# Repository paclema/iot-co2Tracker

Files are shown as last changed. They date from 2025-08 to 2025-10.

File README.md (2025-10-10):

# IoT-CO2Tracker

The IoT-CO2Tracker is a compact device that measures CO₂, temperature, and humidity. Initially developed on an ESP8266, it was later moved to an ESP32 using the IoT-PostBox board. The project also serves to validate the board's capabilities, though that is not its primary purpose.

An external GPS module can be connected via the serial port, allowing the device to publish both sensor readings and location data. This data is sent via LoRaWAN to The Things Network (TTN) for coverage and connectivity analysis, and over Wi-Fi using MQTT to your own broker. When needed, GPS tracks are logged to the onboard flash storage and can be downloaded for visualization through a built-in FTP server. The latest hardware revision includes a 2" TFT screen that displays live sensor values, connectivity, and battery status, with a user interface built on LVGL v9 and designed with SquareLine.

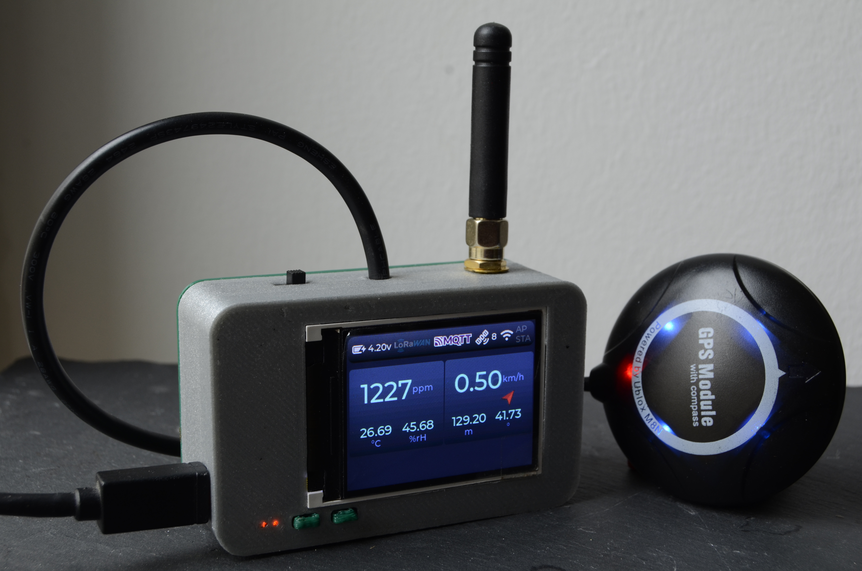
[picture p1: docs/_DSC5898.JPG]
IoT-CO2Tracker


---

## Communication flow

```mermaid
flowchart LR
  	Device[IoT-CO2Tracker]
	Broker[(MQTT Broker)]
	GW[LoRaWAN Gateway]
	TTN[The Things Network]
	NR[Node-RED]
	HA[Home Assistant]
	DB[(InfluxDB)]
	G[Grafana]
	Flash[(LittleFS)]
	PC[PC]
	Viz[GPSVisualizer]

	Device -- MQTT (JSON) --> Broker
	Broker --> NR
	Device -- LoRaWAN (binary) --> GW --> TTN --> NR
	NR --> DB --> G
		NR -.->|update device*| HA

	Device -- GPS tracks --> Flash -- FTP download --> PC --> Viz
```

<sub>* planned (to be implemented)</sub>

### MQTT
- Topic: `/iot-co2Tracker/<deviceId>/data`

Example payload (without GPS):

```json
{
	"CO2": 222,
	"temp": 33.02967834,
	"humidity": 30.82733154,
	"rssi_STA": -38,
	"vBat": 4.21023798,
	"vBus": 5.021749973,
	"PowerStatus": 2,
	"ChargingStatus": 2
}
```

Example payload (with GPS):

```json
{
	"CO2": 229,
	"temp": 31.5396347,
	"humidity": 29.40368652,
	"lat": 51.27265917,
	"lng": 12.37718133,
	"date": 120925,
	"time": 15070704,
	"speed": 0.11112,
	"satellites": 4,
	"altitude": 197.6,
	"hdop": 8.33,
	"course": 120925,
	"rssi_STA": -54,
	"vBat": 4.116175175,
	"vBus": 0.01325,
	"PowerStatus": 3,
	"ChargingStatus": 1
}
```

### LoRaWAN uplink

| Field | C type | Bytes | Units | Notes |
|---|---|---|---|---|
| latitude | uint32_t | 4 | degrees | 24-bit value scaled to 4 bytes ((lat+90)/180*16777215) |
| longitude | uint32_t | 4 | degrees | 24-bit value scaled to 4 bytes ((lng+180)/360*16777215) |
| altitude | uint16_t | 2 | m |  |
| hdop | uint16_t | 2 | HDOP |  |
| speed | uint16_t | 2 | km/h | value = km/h × 100 |
| satellites | uint8_t | 1 | count |  |
| course | uint16_t | 2 | degrees |  |
| time | uint32_t | 4 | HHMMSScc  | local offset applied |
| vBat | uint16_t | 2 | mV |  |
| vBus | uint16_t | 2 | mV |  |
| CO2 | uint16_t | 2 | ppm |  |
| temp | uint16_t | 2 | °C | value = °C × 100 |
| hum | uint16_t | 2 | % | value = % × 100 |
| powerStatus | uint8_t | 1 | enum |  |
| chargingStatus | uint8_t | 1 | enum |  |

Notes
- Multi-byte fields are big-endian (MSB first).
- Latitude/Longitude use 24-bit effective values packed into 4 bytes (high byte may be 0).
- Total payload length: 33 bytes.

Decoders: see [formaters/](formaters/) for TTN uplink decoders and field mapping.

TTN setup (OTAA)
1. Create an application `co2Tracker` and register a device.
2. Set the device DEVEUI, APPEUI, and APPKEY to your `config.json`.
3. Add the custom uplink decoder from [formaters/custom](formaters/custom) to your TTN application.
4. Join the device and verify uplinks in the TTN console under the [Application live data tab](https://eu1.cloud.thethings.network/console/applications/co2tracker/data).

### FTP GPS logs
- If the `local_logs` configuration is enabled in the [config.json](data/config/config.json) file, GPS log files will be created on the LittleFS partition. The file names will follow a specific naming convention, such as [`GPS_2025_9_10.csv`](/docs/GPS_2025_9_10.csv).
- Connect via FTP to the device server using the username and password configured in [config.json](data/config/config.json) to download the GPS log file.
- CSV columns follow:

```csv
time,latitude,longitude,altitude,speed,hdop,satellites,course,vBat,vBus,PowerStatus,ChargingStatus,co2,temp,hum
18182040,51.27235567,12.37730017,115.1,31.503,1.06,12,162.6,3.98449,0.00795,1,2,239,22.34,57.10
18182553,51.27197583,12.37750567,115.6,31.540,1.06,12,162.8,3.98449,0.00795,1,2,232,22.34,57.15
18183040,51.27155317,12.37771250,116.4,29.595,1.06,12,167.4,3.98073,0.00795,1,2,221,22.36,57.19
18183541,51.27119583,12.37782367,117.2,29.058,1.15,12,167.5,3.98073,0.00795,1,2,207,22.38,57.31
```
- You can visualize the GPS tracks using tools like [GPSVisualizer](http://www.gpsvisualizer.com/) by uploading the CSV file. A good filter in this case can the [IoT-CO2Tracker GPSVisualizer configuration](https://www.gpsvisualizer.com/map_input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) option.

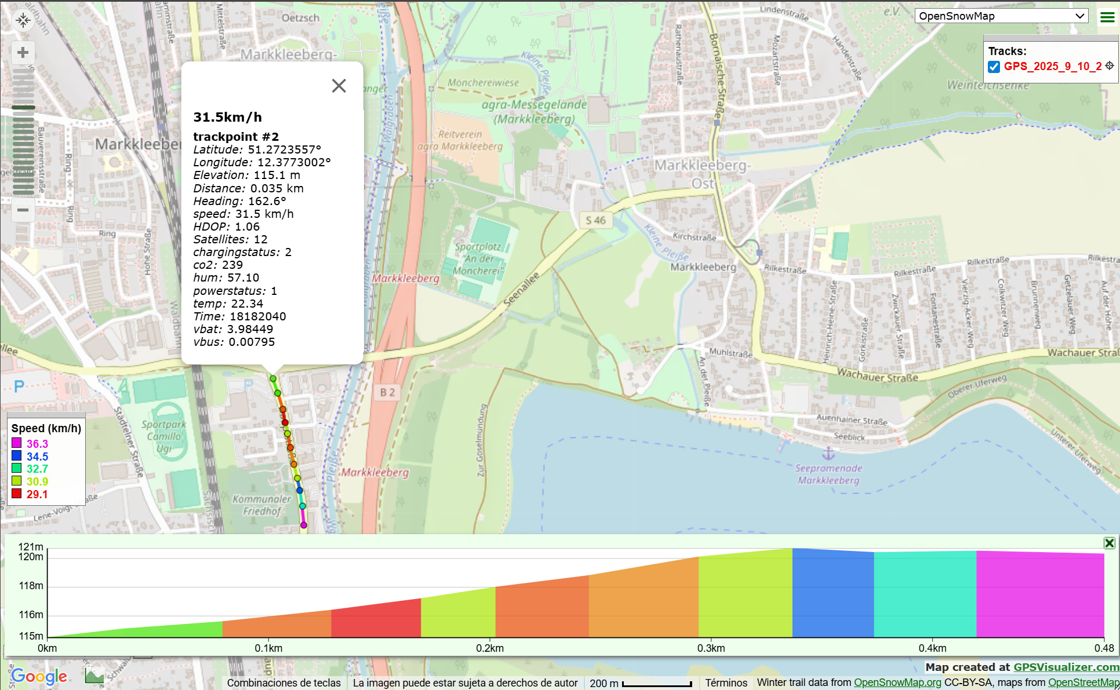
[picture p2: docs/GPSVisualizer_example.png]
GPSVisualizer_example

---

## Software

### Firmware
- PlatformIO project (ESP32). FreeRTOS tasks for sensors, UI, and communications.
- Main Libraries used: 
  - [WebConfigServer](https://github.com/paclema/WebConfigServer): to configure the device settings over a web interface and manage multiple common services
  - [MQTTClient](https://github.com/paclema/MQTTClient): MQTT client library
  - [LoRaWANClient](https://github.com/paclema/LoRaWANClient): LoRaWAN C++ client based on [Arduino-LMIC](https://github.com/mcci-catena/arduino-lmic)
  - [PowerManagement](https://github.com/paclema/PowerManagement): power management library to read battery and power states
  - [SparkFun SCD30](https://github.com/sparkfun/SparkFun_SCD30_Arduino_Library): read CO₂, temperature, and humidity from the SCD30 sensor
  - [TinyGPSPlus](https://github.com/mikalhart/TinyGPSPlus): parse GPS data

### Display & User Interface (UI-LCD)

- Designed for a 2.0" GMT020-02 TFT SPI LCD (ST7789V driver, non-touch).
- Uses LVGL v9.
- Interface designed with SquareLine. The project can be found under [`SquareLineProject/`](SquareLineProject/).

<p align="center">
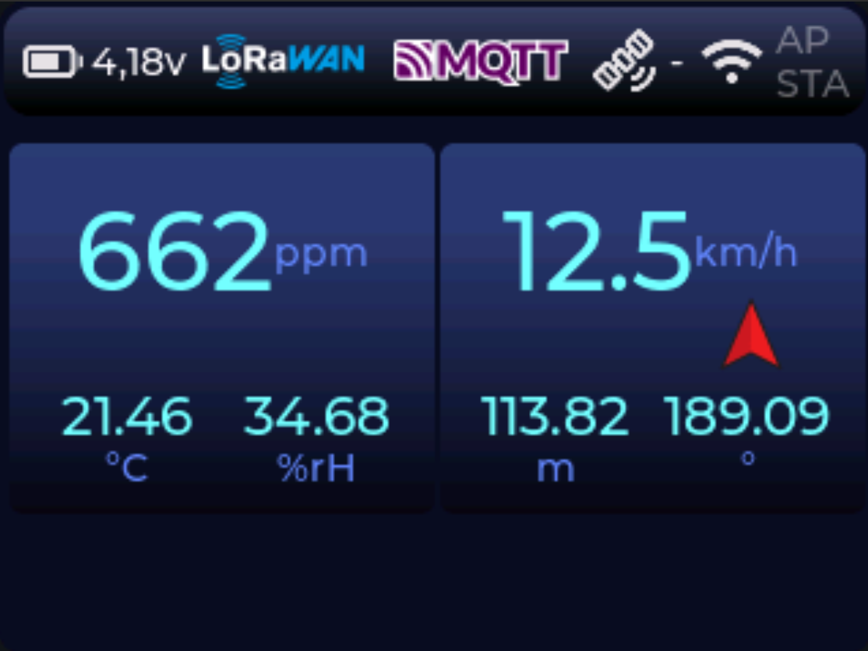
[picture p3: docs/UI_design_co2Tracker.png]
UI Design
  
</p>

### Backend services

- **Node-RED** subscribes to MQTT and TTN, processes messages, and stores data values in InfluxDB (requires [node-red-contrib-influxdb](https://flows.nodered.org/node/node-red-contrib-influxdb) node installation).
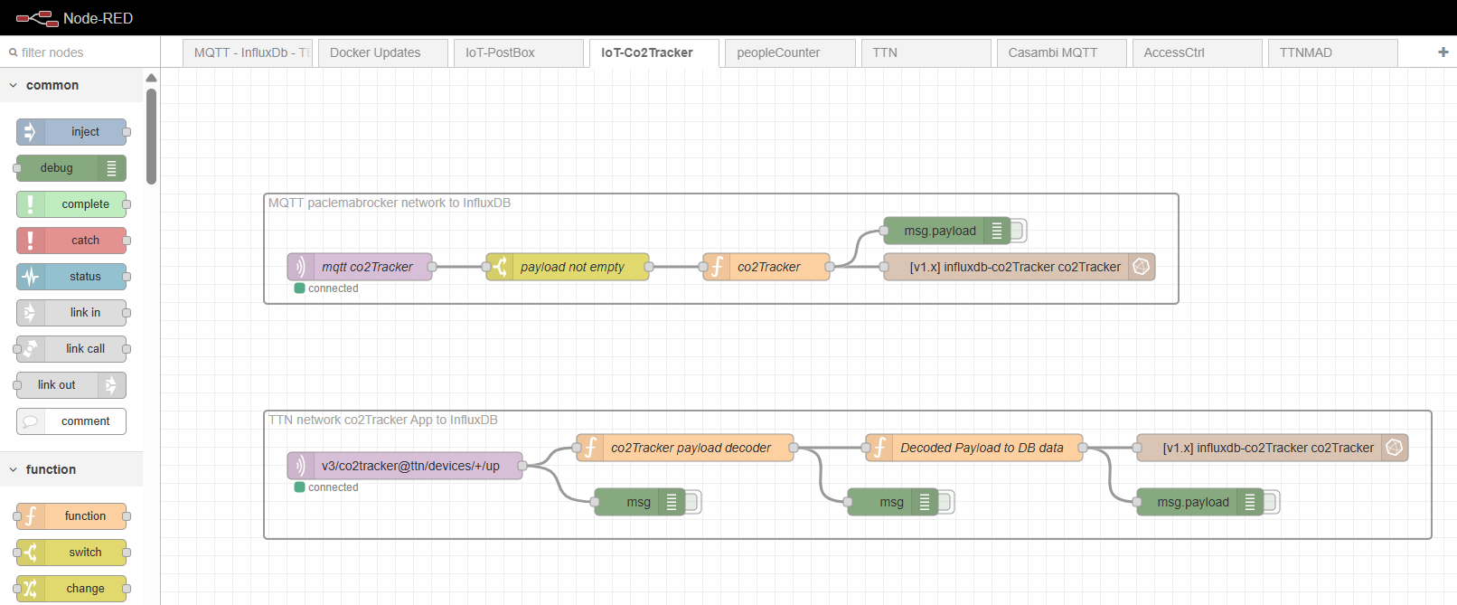
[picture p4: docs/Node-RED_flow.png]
Node-RED_flow

- Example Node-RED flow: [backend/nodered/flows.json](backend/nodered/flows.json)
- **Grafana** dashboards read from InfluxDB.
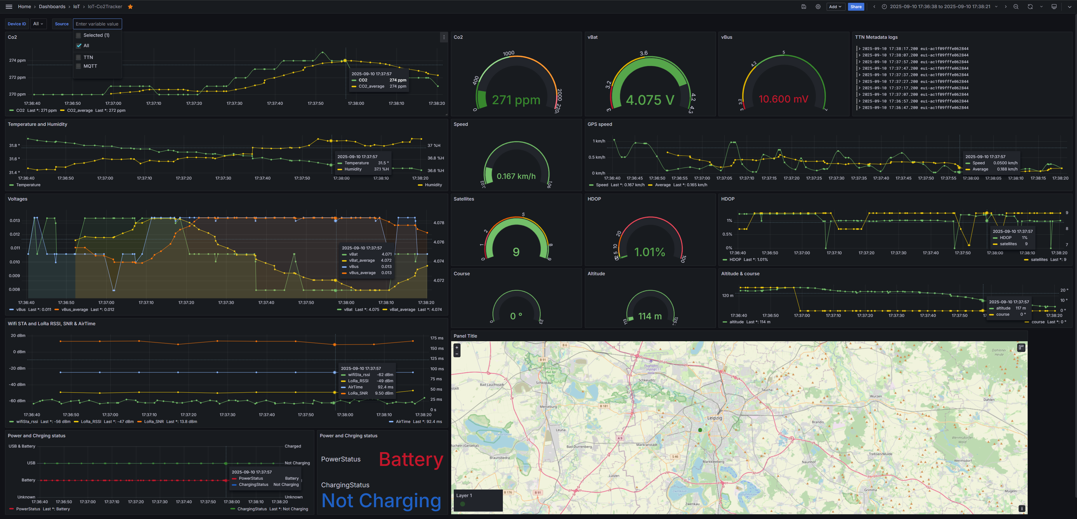
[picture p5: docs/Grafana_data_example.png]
Grafana_data_example

- Example Grafana dashboard: [backend/grafana/IoT-Co2Tracker_dashboard.json](backend/grafana/IoT-Co2Tracker_dashboard.json)
- **TTN formatters**: see decoders in [formaters/](formaters/) for field mapping.

---

## Hardware

### Main Components

The essential hardware components for this project include:
- Board: IoT-PostBox (ESP32/ESP32-S2 with onboard RFM95W LoRa module)
- Sensor: SCD30 (CO₂, temperature, humidity) over I²C
- GPS (optional): u-blox M8N or compatible GPS module using serial UART
- Display (optional): 2.0" GMT020-02 TFT OLED SPI LCD with ST7789V driver
- Power: battery support with charging capabilities using IoT-PostBox

### 3D Design & Enclosure

- FreeCAD sources in [3Ddesigns/](3Ddesigns/)
- External STL references documented in [3Ddesigns/lib/readme.md](3Ddesigns/lib/readme.md).

### Pinout

Pinout highlights (see [boards/](boards/) and [boards/variants/iotpostbox_v1/](boards/variants/iotpostbox_v1/) for full mapping)

**TODO: add pinout diagram**

---

## Build & flash
1. Open the project using PlatformIO with VS Code.
2. Configure services and device following the [WebConfigServer](https://github.com/paclema/WebConfigServer) style, editing the [`data/config/config.json`](/data/config/config.json) and uploading the Filesystem Image to the device.
3. Build and upload the firmware to an IoT-PostBox device.
4. Use the device WebConfigServer UI web portal for advanced options.

---

This repo is derived from [iot_button#CO2_tracker](https://github.com/paclema/iot_button/tree/CO2_tracker)

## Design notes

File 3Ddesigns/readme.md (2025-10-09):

# co2Tracker Case

This folder contains the FreeCAD design files and exported assets for the enclosure of the co2Tracker device.

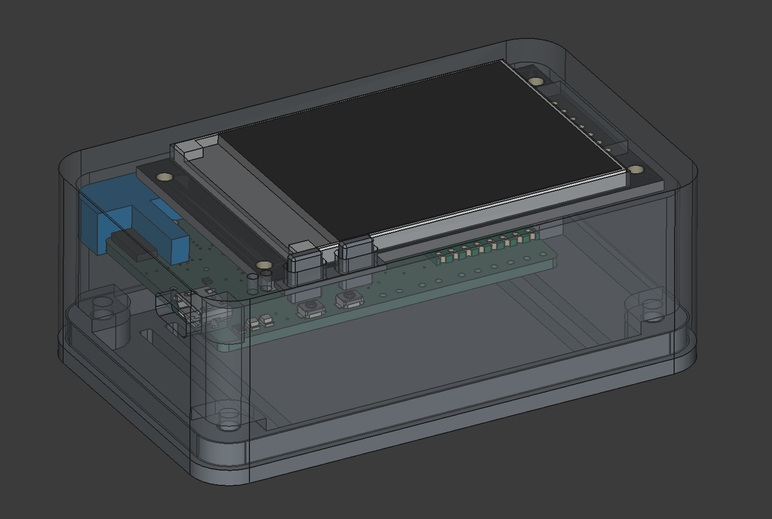
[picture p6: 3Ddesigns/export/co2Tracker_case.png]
Case Render


## Contents

- **FreeCAD Project:**  
  - `co2Tracker_case.FCStd` — Main editable FreeCAD file for the enclosure design.

- **Exports:**  
  - `co2Tracker_case_Top.stl` — STL file for the top part of the case.
  - `co2Tracker_case_Bottom.stl` — STL file for the bottom part of the case.
  - `co2Tracker_case_Board_spacer.stl` — Spacer for mounting the board.
  - `co2Tracker_case_Buttons_extender.stl` — Extender for external buttons.

## Description

The case is designed to fit the IoT-PostBox board, SCD30 sensor, GPS module, TFT display, and a 1100mAh LiPo battery.  
It provides protection and mounting points for all components, with cutouts for the display, connectors, and ventilation for the CO₂ sensor.

**Rear Features:**  
- Holes for mounting the LoRa antenna  
- Cutout for a switch to activate the battery  
- Opening for routing the cable of the external GPS module

**Parametric Design:**  
The enclosure is fully parametric and can be easily modified by adjusting the variable table in the FreeCAD spreadsheet. This allows you to adapt the case to different hardware layouts or dimensions.

**Assembly:**  
- Requires 4x M3x5mm screws for mounting.

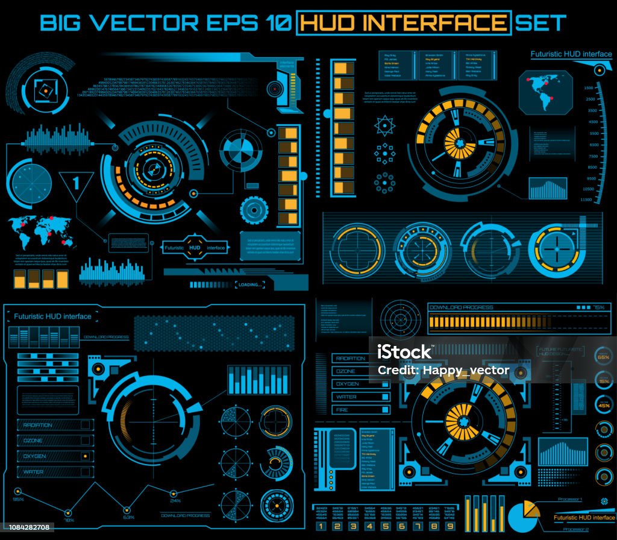
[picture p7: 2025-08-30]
SquareLineProject/assets/istockphoto-1084282708-1024x1024.jpg

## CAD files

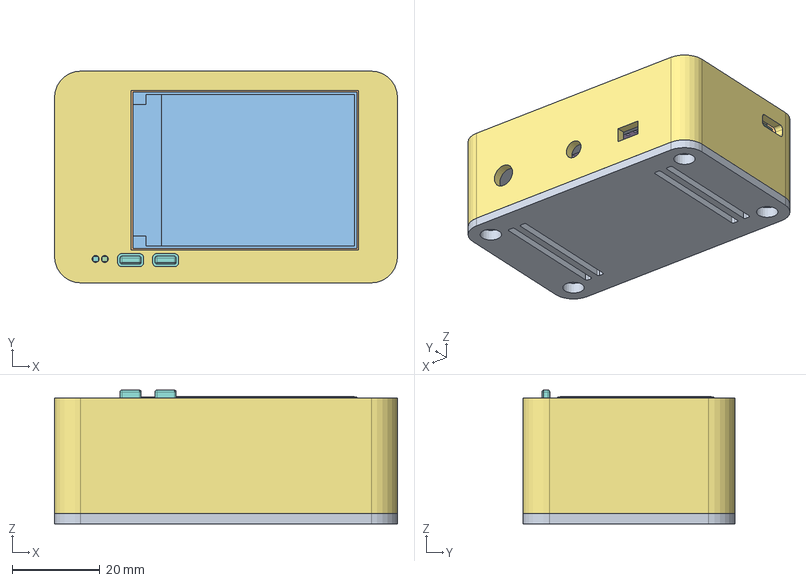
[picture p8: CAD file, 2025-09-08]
3Ddesigns/co2Tracker_case.FCStd
78.4 x 48.4 x 30.6 mm
Bottom_lid&bolt_support
GMT020-02 Ver:1.1 LCD v2
GMT020-02 Ver:1.1 LCD v003
USB_Micro-B_Molex_47346-0001
QFN-56-1EP_7x7mm_P0.4mm_EP5.6x5.6mm
QFN 28 v2
QFN 28 v003
QFN 28 v004
QFN 28 v005
QFN 28 v006
QFN 28 v007
QFN 28 v008
QFN 28 v009
QFN 28 v010
QFN 28 v011
QFN 28 v012
QFN 28 v013
QFN 28 v014
QFN 28 v015
QFN 28 v016
QFN 28 v017
QFN 28 v018
QFN 28 v019
QFN 28 v020
QFN 28 v021
QFN 28 v022
QFN 28 v023
QFN 28 v024
QFN 28 v025
QFN 28 v026
QFN 28 v027
QFN 28 v028
QFN 28 v029
QFN 28 v030
QFN 28 v031
QFN 28 v032
QFN 28 v033
QFN 28 v034
QFN 28 v035
QFN 28 v036
QFN 28 v037
QFN 28 v038
QFN 28 v039
QFN 28 v040
QFN 28 v041
QFN 28 v042
QFN 28 v043
QFN 28 v044
QFN 28 v045
QFN 28 v046
QFN 28 v047
QFN 28 v048
QFN 28 v049
QFN 28 v050
QFN 28 v051
QFN 28 v052
QFN 28 v053
QFN 28 v054
QFN 28 v055
QFN 28 v056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

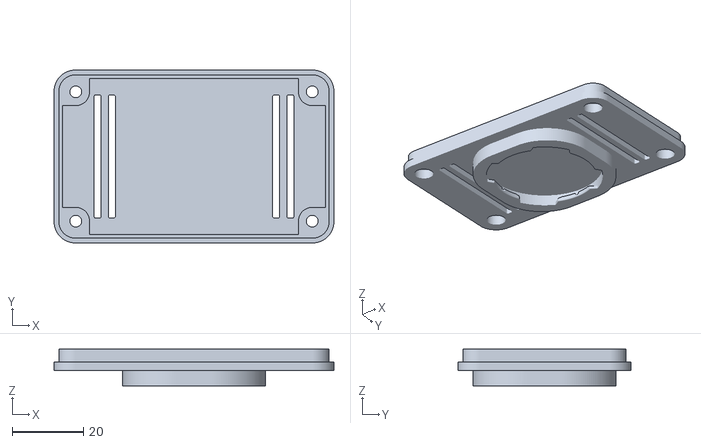
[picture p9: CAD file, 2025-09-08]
3Ddesigns/export/co2Tracker_case_Bottom_QuadLock.stl
78.4 x 48.4 x 10.3

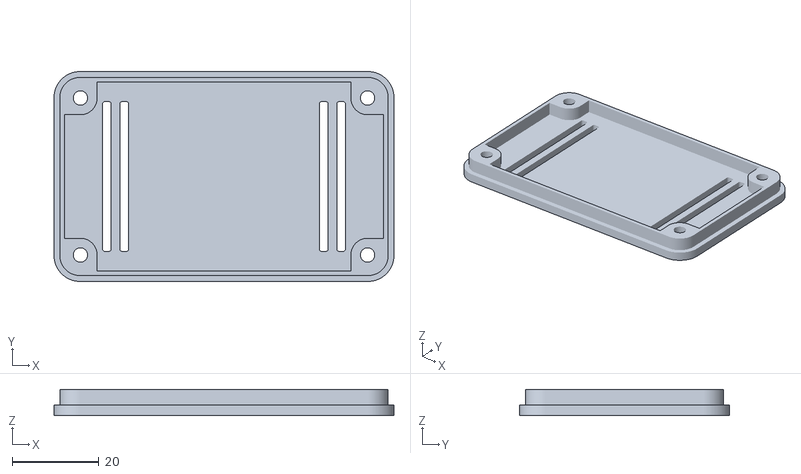
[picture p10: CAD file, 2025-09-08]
3Ddesigns/export/co2Tracker_case_Bottom.stl
78.4 x 48.4 x 6.00

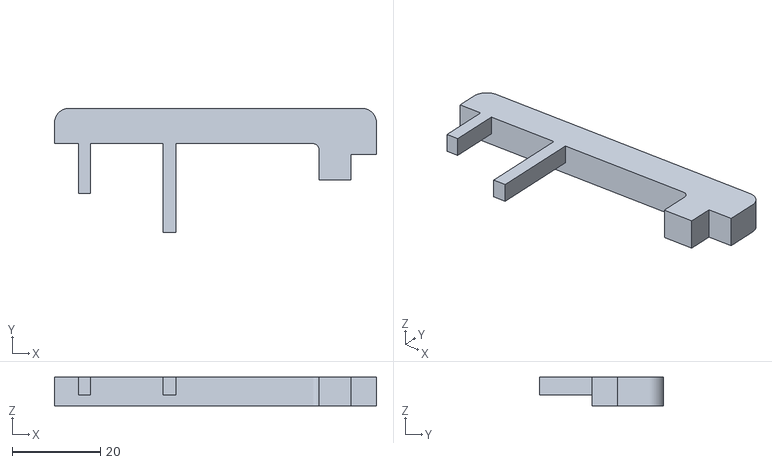
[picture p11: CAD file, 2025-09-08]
3Ddesigns/export/co2Tracker_case_Board_spacer.stl
73.0 x 28.2 x 6.51

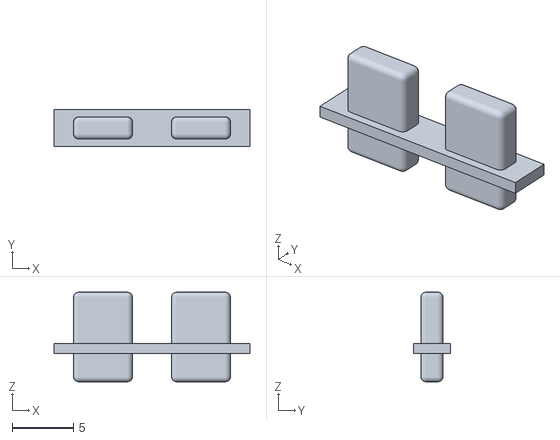
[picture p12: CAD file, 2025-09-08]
3Ddesigns/export/co2Tracker_case_Buttons_extender.stl
16.0 x 3.00 x 7.32

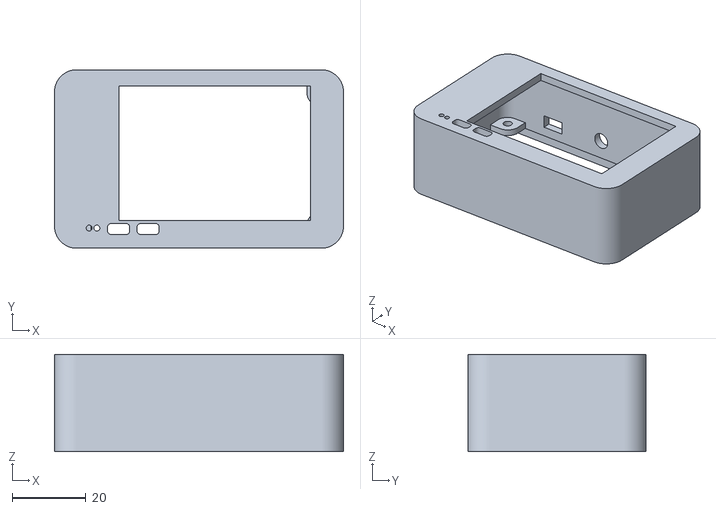
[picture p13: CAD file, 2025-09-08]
3Ddesigns/export/co2Tracker_case_Top.stl
78.4 x 48.4 x 26.4

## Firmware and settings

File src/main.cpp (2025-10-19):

#include <Arduino.h>


// Main variables:
// #define DEBUG_ESP_CORE

// Enable wifi diagnostic using platformio build_glag: -D ENABLE_SERIAL_DEBUG:
#define ENABLE_SERIAL_DEBUG true


// Device configurations
unsigned long currentLoopMillis = 0;
unsigned long previousMainLoopMillis = 0;
size_t totalBytes;
size_t usedBytes;
size_t freeBytes;
unsigned long previousSPIFFSLoopMillis = 0;
#define SPIFFS_CHECK_SPACE_TIME 5000


// WebConfigServer Configuration
#include "WebConfigServer.h"
WebConfigServer config;   // <- global configuration object

#include <Co2Tracker.h>
Co2Tracker* co2Tracker = nullptr;

#include <OneButton.h>
#define BUTTON_PIN 0
OneButton button0(BUTTON_PIN, true);

// TFT screen and LVGL UI
#include <lvgl.h>
#include <TFT_eSPI.h>
#include <ui.h>
unsigned long lvHandlerTimerStart = 0;
unsigned long lvHandlerTimerElapsed = 0;

enum { SCREENBUFFER_SIZE_PIXELS = TFT_WIDTH * TFT_HEIGHT / 10 };
static lv_color_t buf [SCREENBUFFER_SIZE_PIXELS];

TFT_eSPI tft = TFT_eSPI( TFT_WIDTH, TFT_HEIGHT ); /* TFT instance */

#if LV_USE_LOG != 0
void my_print(const char * buf) {
  Serial.printf(buf);
  Serial.flush();
}
#endif

void my_disp_flush (lv_display_t *disp, const lv_area_t *area, uint8_t *pixelmap){
  uint32_t w = ( area->x2 - area->x1 + 1 );
  uint32_t h = ( area->y2 - area->y1 + 1 );

  // if (LV_COLOR_16_SWAP) {
  //     size_t len = lv_area_get_size( area );
  //     lv_draw_sw_rgb565_swap( pixelmap, len );
  // }

  tft.startWrite();
  tft.setAddrWindow( area->x1, area->y1, w, h );
  tft.pushColors( (uint16_t*) pixelmap, w * h, true );
  tft.endWrite();

  lv_disp_flush_ready( disp );
}

static uint32_t my_tick_get_cb (void) { return millis(); }

#if defined(ARDUINO_IOTPOSTBOX_V1) || defined(ESP32)
#include "PowerManagement.h"
#include "freertos/FreeRTOS.h"
#include "freertos/task.h"
#define POWER_UI_UPDATE_DELAY_MS 1000
PowerManagement power;
TaskHandle_t powerChargeCbTaskHandle = nullptr;

// Task to update the battery icon on charging status change
#include "battery_ui.h"
void powerChargeCbTask(void *pvParameters) {
  (void)pvParameters;
  PowerStatus lastStatus = power.getPowerStatus();
  for (;;) {
    ulTaskNotifyTake(pdTRUE, portMAX_DELAY); // Wait for notification
    PowerStatus currentPowerStatus = power.getPowerStatus();
    if (currentPowerStatus != lastStatus) {
      lastStatus = currentPowerStatus;
      update_battery_icon(power, (float)power.vBatSense.mV / 1000.0);
    }
  }
}

// Callback to notify the icon task from PowerManagement
void onChargingStatusChanged(void) {
  BaseType_t xHigherPriorityTaskWoken = pdFALSE;
  if (powerChargeCbTaskHandle) {
    vTaskNotifyGiveFromISR(powerChargeCbTaskHandle, &xHigherPriorityTaskWoken);
    portYIELD_FROM_ISR(xHigherPriorityTaskWoken);
  }
}

// FreeRTOS task to update power and LVGL label
void powerUpdateTask(void *pvParameters) {
  (void)pvParameters;
  char batStr[8];
  for (;;) {
    power.update();
    float voltage = (float)power.vBatSense.mV / 1000.0;
    snprintf(batStr, sizeof(batStr), "%1.2fv", voltage);
    lv_lock();
    lv_label_set_text(ui_batVal, batStr);
    lv_unlock();
    update_battery_icon(power, voltage);
    vTaskDelay(pdMS_TO_TICKS(POWER_UI_UPDATE_DELAY_MS));

  }
}
#endif


// Websocket functions to publish:
String getLoopTime(){ return String(currentLoopMillis - previousMainLoopMillis);}
String getLVGLHandlerElapsed(){ return String(lvHandlerTimerElapsed);}
String getRSSI(){ return String(WiFi.RSSI());}
String getHeapFree(){ return String((float)GET_FREE_HEAP/1000);}
String getMemoryUsageString(){ 
  String r = String("\"Used: " + config.formatBytes(usedBytes) + " Free: " +  config.formatBytes(freeBytes) + "\"");
  // Serial.println(r);
  return r;}
String getMemoryFree(){  return String(freeBytes);};
String getVBat(){ return String((float)power.vBatSense.mV/1000,4);}
String getVBus(){ return String((float)power.vBusSense.mV/1000,3);}



void setup() {
  // esp_log_level_set("i2c.master", ESP_LOG_NONE);
  Serial.begin(115200);

  #ifdef ENABLE_SERIAL_DEBUG
    Serial.setDebugOutput(true);
  #endif

  button0.attachClick([]() {
    digitalWrite(LDO2_EN_PIN, !digitalRead(LDO2_EN_PIN));
  });

  Serial.println("###  LVGL setup\n");
  Serial.printf("LVGL V%d.%d.%d\n", lv_version_major(), lv_version_minor(), lv_version_patch());
  lv_init();

#if LV_USE_LOG != 0
  lv_log_register_print_cb( my_print ); /* register print function for debugging */
#endif

  tft.init(TFT_BLACK);
  // tft.begin();          /* TFT init */
  // tft.fillScreen(TFT_BLACK);
  tft.setRotation( TFT_ROTATION );

  static lv_disp_t* disp;
  disp = lv_display_create( TFT_WIDTH, TFT_HEIGHT );
  lv_display_set_buffers( disp, buf, NULL, SCREENBUFFER_SIZE_PIXELS * sizeof(lv_color_t), LV_DISPLAY_RENDER_MODE_PARTIAL );
  lv_display_set_flush_cb( disp, my_disp_flush );

  lv_tick_set_cb( my_tick_get_cb );

  ui_init();
  lv_timer_handler(); // Call LVGL timer handler first time to refresh the screen earlier

  #if defined(ARDUINO_IOTPOSTBOX_V1) || defined(ESP32)
  // // while(!Serial) {}
  power.setup();
  power.update();
  power.addChargingStatusCallback(onChargingStatusChanged);
  xTaskCreatePinnedToCore(
    powerUpdateTask,
    "PowerUpdateTask",
    2048,
    NULL,
    4,
    NULL,
    0
  );
  xTaskCreatePinnedToCore(
    powerChargeCbTask,
    "powerChargeCbTask",
    1024,
    NULL,
    4,
    &powerChargeCbTaskHandle,
    0
  );
  #endif
  
  co2Tracker = new Co2Tracker();
  co2Tracker->setMQTTClient(config.getMQTTClient());
  
  config.addConfig(co2Tracker, "co2Tracker");
  config.begin();

  // topic = config.getDeviceTopic() + "data";
  co2Tracker->setMQTTDeviceTopic(config.getDeviceTopic() + "data");
  // mqttClient = config.getMQTTClient();
 
  config.addDashboardObject("heap_free", getHeapFree);
  config.addDashboardObject("loop", getLoopTime);
  config.addDashboardObject("LVGL_Handler", getLVGLHandlerElapsed);
  config.addDashboardObject("RSSI", getRSSI);
  config.addDashboardObject("SPIFFS_Usage", getMemoryUsageString);
  config.addDashboardObject("SPIFFS_Free", getMemoryFree);
  config.addDashboardObject("VBat", getVBat);
  config.addDashboardObject("VBus", getVBus);

  

  co2Tracker->begin();

  Serial.println("###  Looping time\n");

}

void loop() {
  button0.tick();
  
  lvHandlerTimerStart = millis();
  lv_timer_handler();
  lvHandlerTimerElapsed = millis() - lvHandlerTimerStart;

  currentLoopMillis = millis();
  if (currentLoopMillis - previousSPIFFSLoopMillis > SPIFFS_CHECK_SPACE_TIME){
    previousSPIFFSLoopMillis = currentLoopMillis;
    totalBytes = LittleFS.totalBytes();
    usedBytes = LittleFS.usedBytes();
    freeBytes  = totalBytes - usedBytes;
  }
  config.loop();
  co2Tracker->loop();


  /// TODO. SET RECONECTION CALLBACK!!
  ///********************************* */
  // Reconnection loop:
  // if (WiFi.status() != WL_CONNECTED) {
  //   config.begin();
  //   networkRestart();
  //   config.configureServer(&server);
  // }

  previousMainLoopMillis = currentLoopMillis;
}

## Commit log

2021-08-10 Added first version
    [default.csv, default_16MB.csv]
2021-12-22 Fixed espressif32@3.2.0 platform for targets using lwip_enabled custom arduino-esp32 core version
2022-07-09 Added board IoT-PostBox_v1 as pio target
2022-07-12 Added PowerManagement for IoT-postbox_v1 target and set mqtt payload buffer size dinamically
2022-07-15 Fixed IoT-PostBox_v1 partition table
    [iotpostboxv1_16MB.csv]
2025-08-18 Add testing PostBox_v1_NEW and ESP32_NEW using latest esp32 platform and PowerManagement & WebConfigServer lib versions.
2025-08-18 Replace PubSubClient with MQTTClient
    [main.cpp]
2025-08-18 Add partition scheme default_noOTA for ESP32 to increase app0 size
    [default_noOTA.csv]
2025-08-18 Add IoT-PostBox v1 board json
2025-08-18 Add IoT-PostBox v1 variant files
    [partitions.csv]
2025-08-18 Change platform-espressif32 to v3.1.2 to avoid I2C current issues
2025-08-18 Replace mqtt wifiSta_rssi object to rssi_STA
    [main.cpp]
2025-08-18 Added missing PowerStatus and ChargingStatus to LoRa payload
2025-08-18 Added lat and long filter for null close values for payload custom formater
2025-08-18 Replace logging macros with ESP_LOG functions and include RSSI, SPIFFS_Usage and SPIFFS_Free into WebConfigServer dashboard
    [main.cpp]
2025-08-20 Clean up ESP32 pio target configs
2025-08-21 Fix LoRaWANClient onEvent function as global as required for arduino lmic and fix its callbacks for Co2Tracker class
2025-08-21 Remove prints on LoRaWANClient::send method
2025-08-26 Implement xTasks to update power and battery ui info on separate threads instead of in loop and set charging status callback to detect charging change interrupts
2025-08-26 Add battery UI update functionality and refactor power status handling on batery_ui.h
2025-08-26 Update GPS and Co2 sensor data in UI display
2025-08-27 Reduce task stack sizes for power management
2025-08-30 Fix removed currentLoopMillis update on main loop
    [main.cpp]
2025-08-30 Fix currentLoopMillis update position in loop function
    [main.cpp]
2025-08-30 Update SPI frequency settings and add delay in TFT initialization
2025-09-08 Add FreeCAD design files, exported stls and README for co2Tracker case
    [co2Tracker_case.FCStd, co2Tracker_case_Board_spacer.stl, co2Tracker_case_Bottom.stl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]
2025-09-08 Design case bottom version with QuadLock socket and export co2Tracker_case_Bottom_QuadLock.stl
    [co2Tracker_case_Bottom_QuadLock.stl]
2025-09-08 Add external STL models and update README for enclosure design libs
2025-09-12 Increase MQTT JSON size, reduce default GPS data publish to 5s and set LoRa SF7 and 14 dBi transmission power by default
2025-09-12 Add README and doc images
    [GPS_2025_9_10.csv]
2025-09-12 Add LoRaWAN uplink details to README and create initial Node-RED flows and Grafana dashboard configuration
2025-09-12 Insert temporary IoT-CO2Tracker image into README
2025-09-16 Add OneButton library integration and implement button press functionality to toggle display power
2025-10-06 Add Node-RED JSON flow
2025-10-06 Update Node-RED JSON with correct flow
2025-10-09 Update README.md to specify battery type in case description
2025-10-19 Clean up platformio.ini configurations and extend PowerManagement use to ESP32 targets
2025-10-19 Rename default_no_ota.csv partition file
    [default_no_ota.csv]
